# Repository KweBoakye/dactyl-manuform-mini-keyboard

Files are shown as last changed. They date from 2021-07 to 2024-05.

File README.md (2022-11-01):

# Dactyl ManuForm Mini Keyboard

This is a fork of the [Dactyl-ManuForm](https://github.com/tshort/dactyl-keyboard). The Dactyl-Manuform is a fork of the [Dactyl](https://github.com/adereth/dactyl-keyboard) with the thumb cluster from [ManuForm](https://github.com/jeffgran/ManuForm).

# Custom Dactyl Mini
A Dactyl Mini completely reworked to use Affine Transformations, Bezier Curves and splines and Openscads Polyhedrons to build most of the model.

It has per column Stagger, Splay, Curvature and tilt along with a "flatter" thumb cluster

It also supports a tps-65 trackpad, st7789 screen, GX16 connecters for split transport and a rp2040 plus board
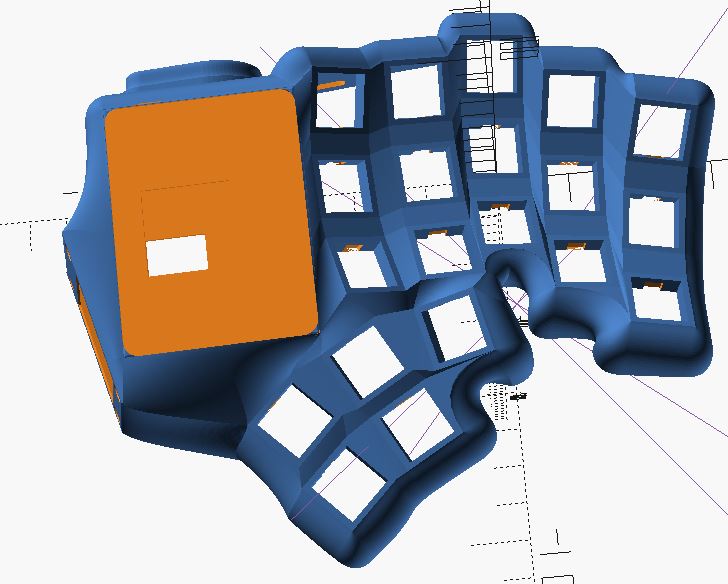
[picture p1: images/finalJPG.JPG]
custom dactyl mini


## Forks

- https://github.com/lebastaq/dactyl-manuform-mini-keyboard
- [Dactyl ManuForm Tight Keyboard](https://github.com/okke-formsma/dactyl-manuform-tight)
- https://github.com/carbonfet/dactyl-manuform
- [Track Beast](https://github.com/davekincade/dactyl-manuform-mini-keyboard/tree/dk-track-beast)
- [Tractyl ManuForm Keyboard](https://github.com/noahprince22/tractyl-manuform-keyboard)
- [Compactyl](https://github.com/dereknheiley/dactyl-manuform-tight)

## Features

- The use of sidenubs can be disabled. Sidenub should be disabled if you use Kailh, and Outemu. If you use Cherry MX, Gateron or Zealios switches, you can enable the sidenubs.
- Spaces for rentention tabs are added.
- One key in the thumb cluster has been removed. Other thumb keys are also adjusted.
- The total height is reduced and wire posts are removed. This results in a
  higher printing speed and a lower cost.
- Screw posts are moved inside. The holes are designed for TRISERT® thread inserts 145m3.

- A GX16 Mount is used instead of TRRS, code adapted from https://gist.github.com/jamiehs/de163e7d469e4fb4220e504b58613806
- Blackpill f411 holder adapted from https://github.com/darrenph1/dactyl-keyboard
- oled slot and mounting area (left-section) adapted from https://github.com/oysteinkrog/dactyl-manuform-mini-keyboard
- encoder hole from https://github.com/oysteinkrog/dactyl-manuform-mini-keyboard
- Thumb trackball and thumb area adapted from https://github.com/noahprince22/tractyl-manuform-keyboard
- Tenting stand and palm rest from https://github.com/noahprince22/tractyl-manuform-keyboard
- Adafruit IS31FL3731 screw mounts
- Joycon Joystick mounting (designed for the left hand so has to be mirrored)
- Cirque TM040040 Mount
- Mounting for Toggle Switch with Cover (Example https://thepihut.com/products/illuminated-toggle-switch-with-cover-red)

## Generate OpenSCAD and STL models

* Run `lein generate` or `lein auto generate`
* This will regenerate the `things/*.scad` files
* Use OpenSCAD to open a `.scad` file.
* Make changes to design, repeat `load-file`, OpenSCAD will watch for changes and rerender.
* When done, use OpenSCAD to export STL files

## License

Copyright © 2015-2018 Matthew Adereth, Tom Short and Leo Lou

The source code for generating the models is distributed under the [GNU AFFERO GENERAL PUBLIC LICENSE Version 3](LICENSE).

The generated models are distributed under the [Creative Commons Attribution-ShareAlike 4.0 International (CC BY-SA 4.0)](LICENSE-models).

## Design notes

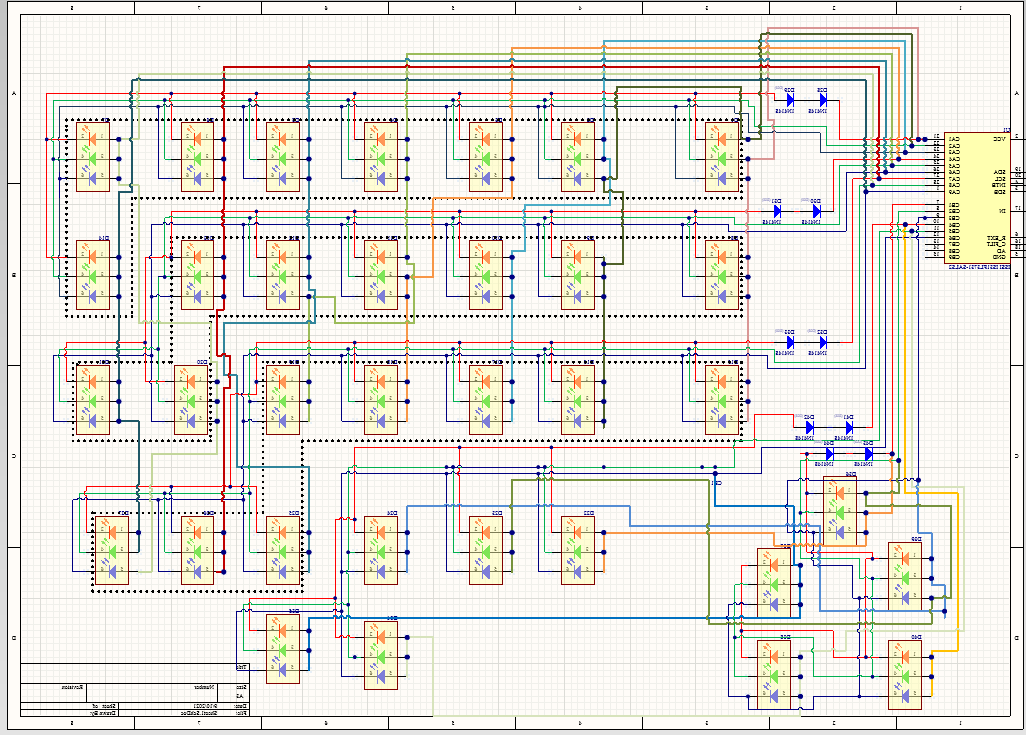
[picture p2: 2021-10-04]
led schematic.png

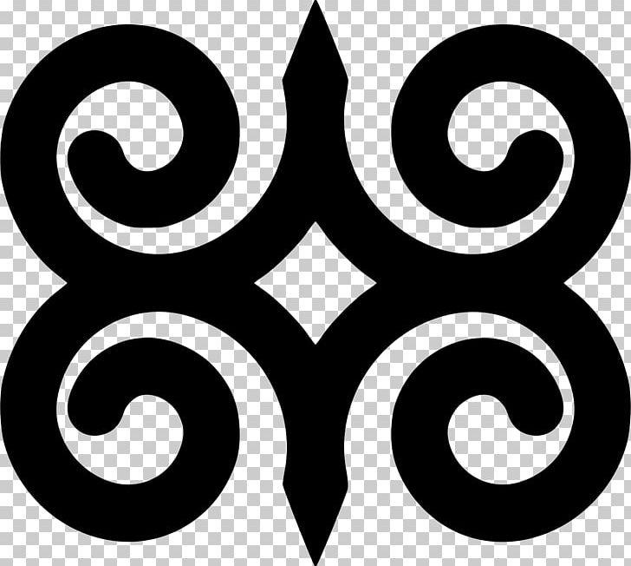
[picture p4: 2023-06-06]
svg/dwennimen.jpg

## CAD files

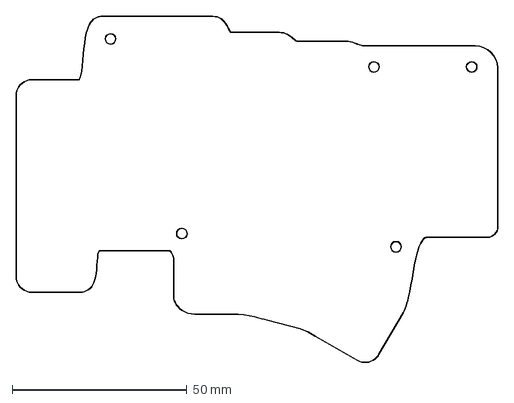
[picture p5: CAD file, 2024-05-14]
parts/bottom_acry_full.dxf
138.0 x 99.2 mm

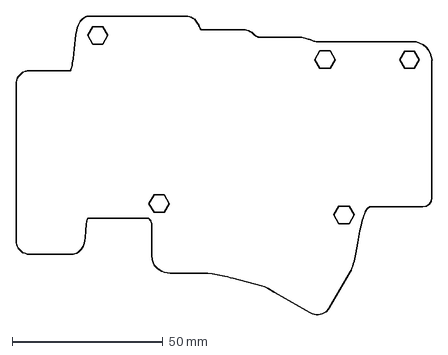
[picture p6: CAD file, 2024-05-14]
parts/mid_acry_full.dxf
138.0 x 99.2 mm

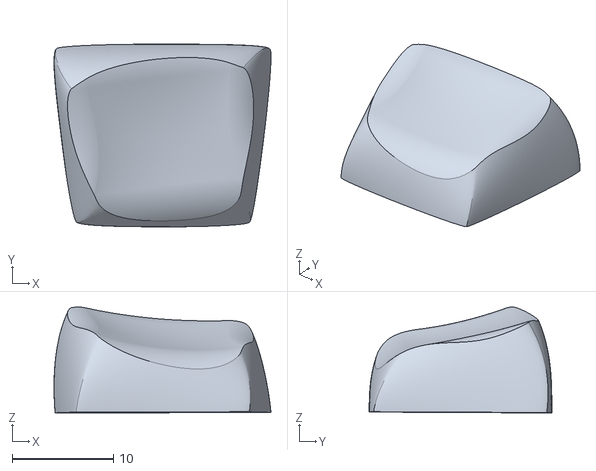
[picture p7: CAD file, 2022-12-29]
parts/caps/C2R.stl
21.5 x 18.1 x 10.5

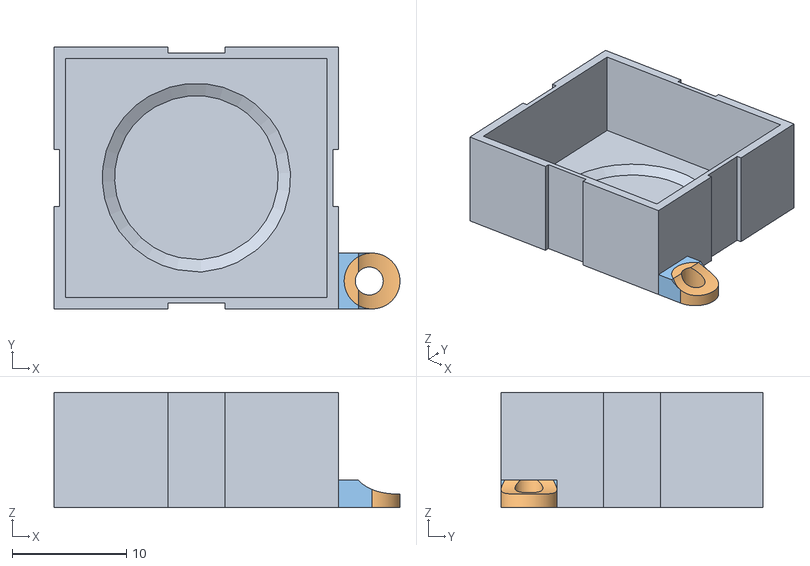
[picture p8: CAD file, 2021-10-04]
things/Joy_Fidget_Cap.obj
30.2 x 22.9 x 10.1

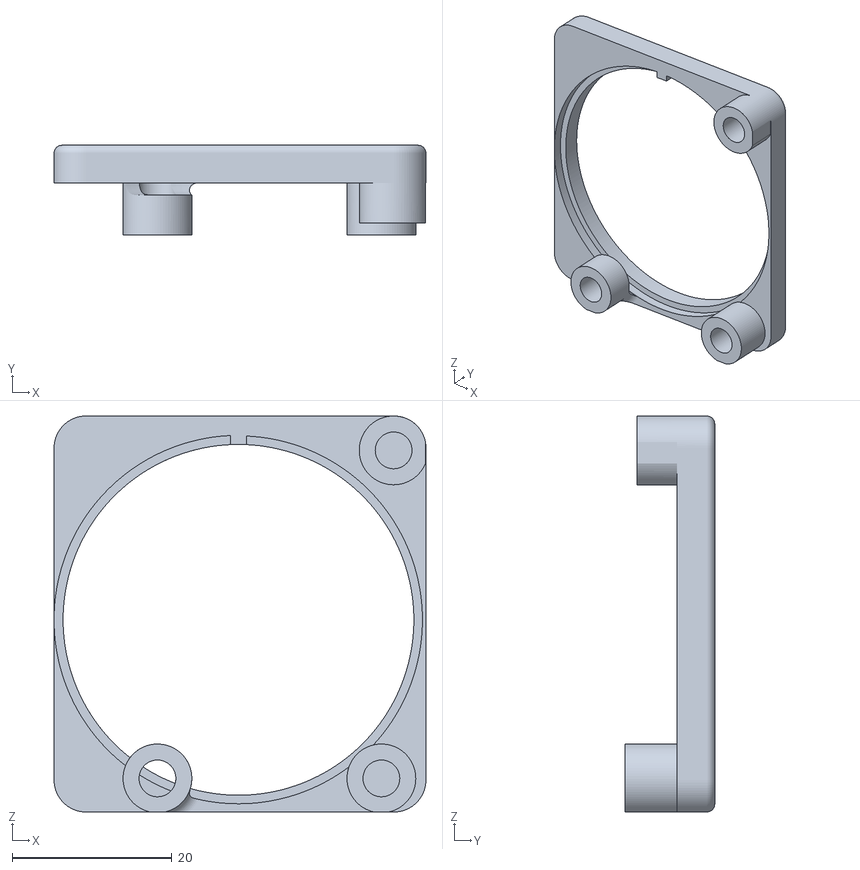
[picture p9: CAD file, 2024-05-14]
parts/top.stl
46.5 x 11.2 x 49.5

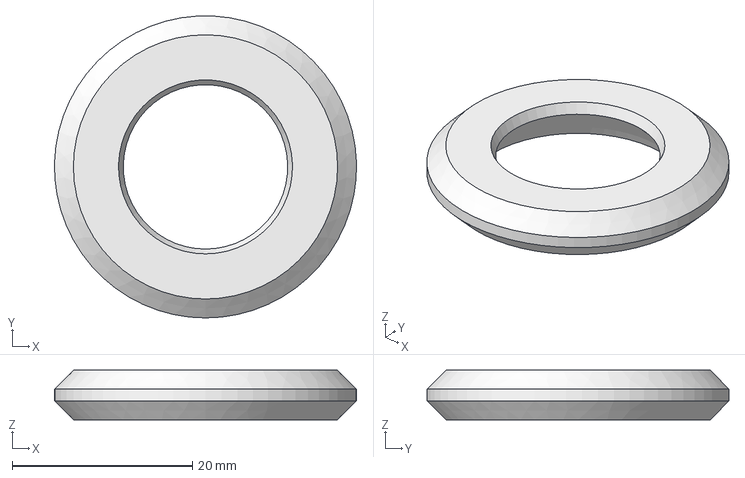
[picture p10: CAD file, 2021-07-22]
things/joystick hole.FCStd
33.5 x 33.5 x 5.50 mm

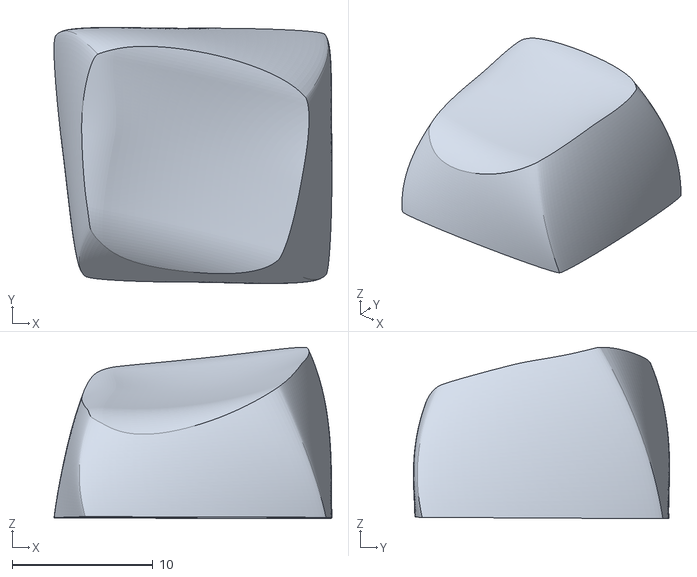
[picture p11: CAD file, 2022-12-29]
parts/caps/C3R.stl
19.8 x 18.2 x 12.2

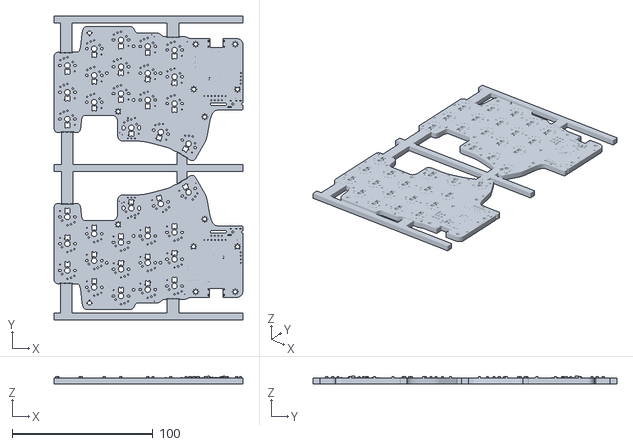
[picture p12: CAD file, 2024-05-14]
parts/dilemma.stl
134.1 x 215.6 x 5.87

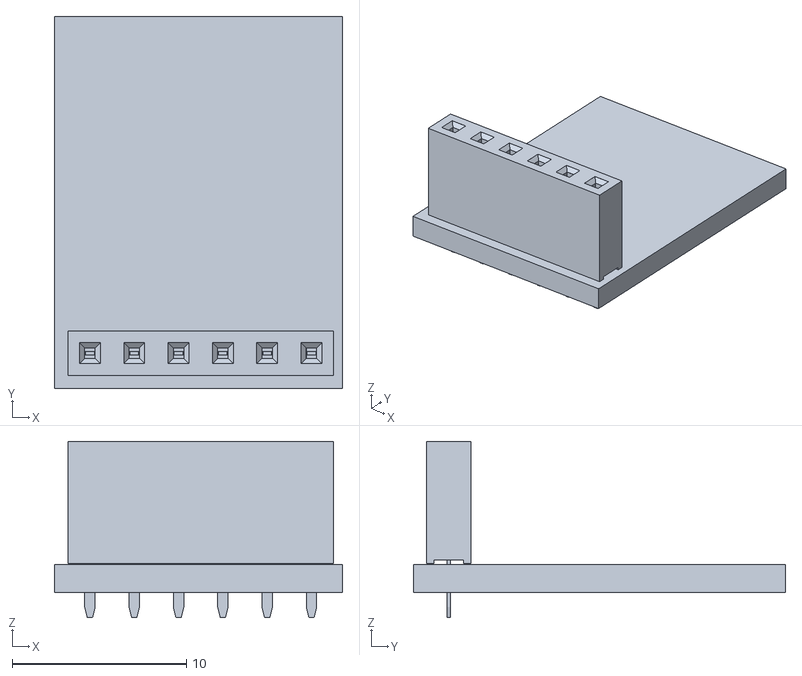
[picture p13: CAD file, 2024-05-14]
parts/azoteq_dilemma_adapter.stl
16.5 x 21.3 x 10.1

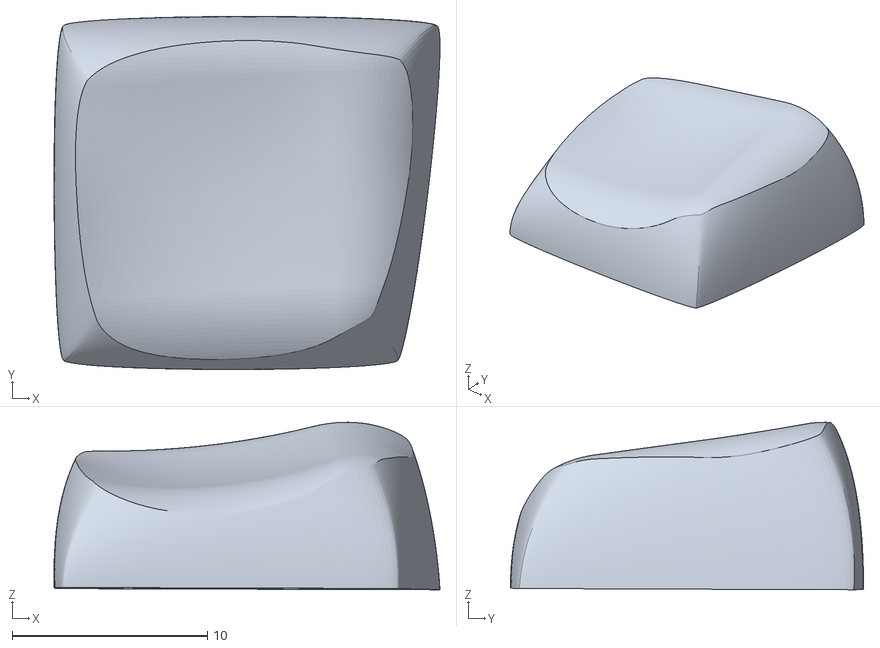
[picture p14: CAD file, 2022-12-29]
parts/caps/C1L.stl
19.8 x 18.1 x 8.58

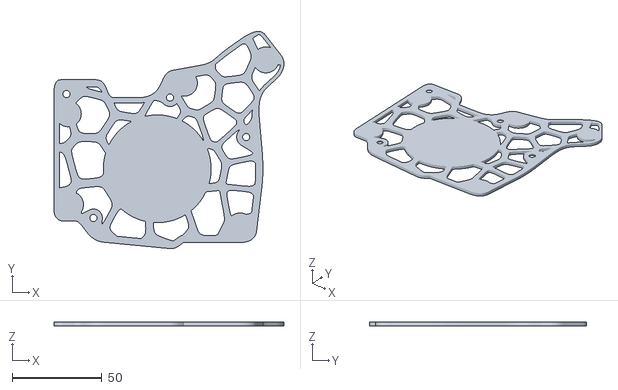
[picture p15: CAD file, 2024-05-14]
parts/magsafe_3dp_v0_1.stl
128.0 x 120.8 x 2.00

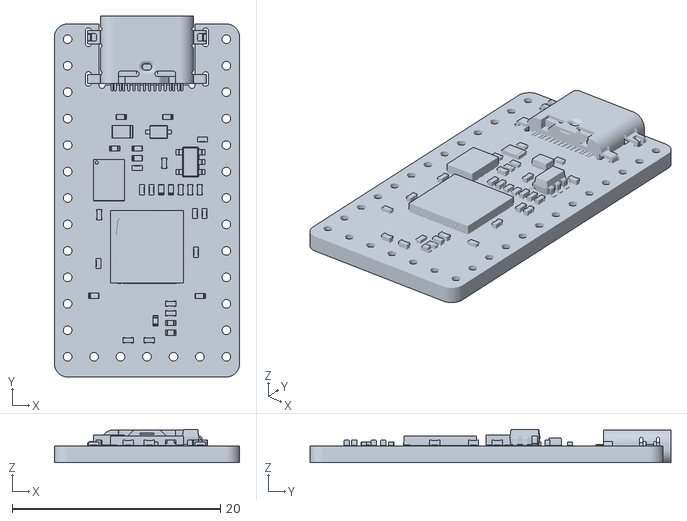
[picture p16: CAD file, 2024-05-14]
parts/Frood-rev7.stl
17.8 x 34.6 x 3.21

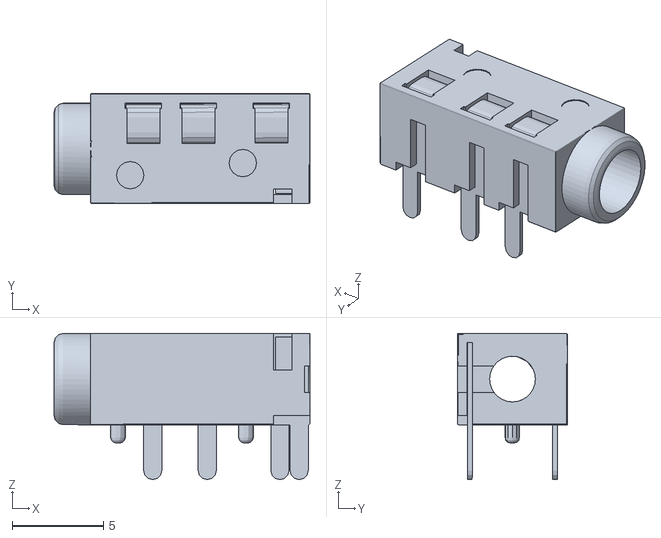
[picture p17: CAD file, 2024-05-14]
parts/pj320a.stl
14.0 x 6.00 x 8.00

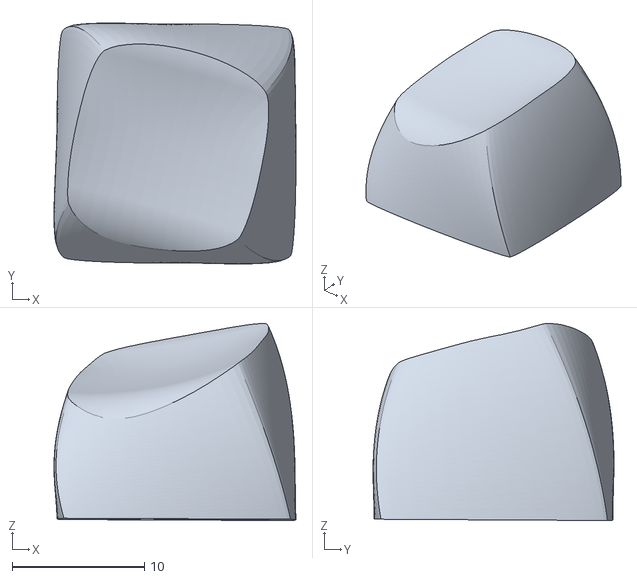
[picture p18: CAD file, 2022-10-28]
parts/caps/DES-kyria-R1T2.stl
18.3 x 18.2 x 14.9

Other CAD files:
parts/caps/C2L.stl
parts/caps/C2R_fixed.stl
parts/caps/C1R.stl
parts/caps/C3L.stl
nutsnbolts/cyl_head_bolt-drawAllScript.scad
nutsnbolts/cyl_head_bolt.scad
nutsnbolts/data-access.scad
nutsnbolts/data-metric_cyl_head_bolts.scad
nutsnbolts/examples.scad
nutsnbolts/materials.scad
parts/2.54mm x 1 Male Header.stl
parts/2305 DRV2605L.stl
parts/IS31FL3743x_Breakout.stl
parts/ImageToStl.com_dt_azc276a02_pcb1_00a.stl
parts/ImageToStl.com_pin header 1x16 th pitch 2.54mm.stl
parts/KLOR_polydactyl_3DP_switchplate.stl
parts/Kailh LP Choc Burnt Orange.stl
parts/Kailh Polia.stl
parts/ST7789.stl
parts/Tps-65-breakout.stl
parts/USB_Type_C_Female_Connector.stl
parts/adafruit kb2040.stl
parts/caps/DES-R1.stl
parts/caps/DES-R2.stl
parts/caps/DES-R3.stl
parts/caps/DES-R4.stl
parts/caps/DES-R5.stl
parts/caps/DES-kyria-R1T0.stl
parts/caps/DES-kyria-R1T1.stl
parts/caps/DES-kyria-R1T3.stl
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

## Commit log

2021-07-04 hole for GX16 Panel mount added hole for usb holder removed to allow for this
2021-07-22 added Elite C holder, reset switch hole, Oled, encoder, fixed plate, fixed screws and tent holes and many other general fixes.
    Right is more or less finished just needs customising to my hand
    , left requires adding of joystick
    [joystick hole.FCStd]
2021-10-04 almost finished
    [IS31FL3731-rgb-plcc-6-diagram.kicad_pcb, IS31FL3731-rgb-plcc-6-diagram.sch, Joy_Fidget_Cap.obj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]
2022-09-10 move to using affine transformations, bezier curves, chained hull and polyhedrons
2022-10-05 conversion to polyhedron finished, bottom-plate added
2022-10-28 further changes
    [DES-R1.stl, DES-R2.stl, DES-R3.stl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]
2022-12-14 further changes, most parts printed and verified
    [2.54mm x 1 Male Header.stl, ImageToStl.com_pin header 1x16 th pitch 2.54mm.stl]
2022-12-29 thumb cluster adjusted and resulting issues fixed thumb walls changed, lra position adjusted work done on tps-65 mount
    [C1L.stl, C1R.stl, C2L.stl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]
2023-03-13 further refactoring done including removal of code not specifically for dactyl into a seperate "lib" folder, more curve algorithms added, including curve fitting. structur of dactyl generation dsl fl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
2023-03-25 further case implementation, work on klor case started and more curve alg work
    [KLOR_polydactyl_3DP_switchplate.stl]
2023-04-29 more parameterisation and magnitude estimation algorithms added, further work on case walls
2023-05-03 case walls and key plate completed
2023-05-03 fractyl bottom plate added
2023-05-17 fractyl almost finished and main work on klor polydactyl case completeted
    [Kailh LP Choc Burnt Orange.stl, USB_Type_C_Female_Connector.stl, pico-r3.stl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]
2023-05-24 both dactyl and klor very nearly ready for print
    [adafruit kb2040.stl, pim452.stl, pin header 2.54-12.stl]
2023-06-06 case tweaks, added wrapper for BOSL2 skin and linear sweep added trackpoint stuff and svg's
2023-06-19 fix fractyl screw hole positions more trackpoint position testing starting to add more documentation
2023-06-21 added openscad libraries
    [cyl_head_bolt-drawAllScript.scad, cyl_head_bolt.scad, data-access.scad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]
2023-08-23 rename oled-holder-height to oled-holder-length add support for ST7789 135*240 to klor case
2023-08-23 add models for tps-65 and tps-43
    [tps-43.stl, tps-65.stl]
2023-08-23 fix fractyl bottom plate screw positions
2023-10-07 update drv2605l stl model path
2023-10-07 improved mount for ST7789 135*240
2023-10-07 Added more mounts for breakout board pcbs and devices and improved existing ones
    [2305 DRV2605L.stl, IS31FL3743x_Breakout.stl, Tps-65-breakout.stl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]
2023-10-07 more case decoration
2023-10-07 added case test output
2023-10-07 playing around with cases for other boards
2024-05-14 tps-43 and screen mount for dilemma v2
2024-05-14 final updates before printing (again)
2024-05-14 added inluded stl's
    [Frood-rev7.stl, ImageToStl.com_dt_azc276a02_pcb1_00a.stl, azoteq_dilemma_adapter.stl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]
